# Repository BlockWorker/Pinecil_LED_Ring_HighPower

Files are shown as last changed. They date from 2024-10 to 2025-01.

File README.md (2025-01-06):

# High-Power Pinecil LED Ring

Inspired by [Herushan's original Pinecil LED ring](https://github.com/Herushan/Pinecil_LED_Ring). See the [full project documentation here](https://blockworker.de/pinecil-led-ring-901/).

This version is designed for three ~0.2W LEDs, resulting in almost 100 lumens of light output.

Features a dedicated LED driver module (to be installed inside the Pinecil case), the LED ring itself, as well as PWM dimming using a [modified version of IronOS](https://github.com/BlockWorker/IronOS-LED).

<center>



</center>

## Build one yourself

Of course, feel free to build your own LED ring based on the designs in this repository. Use them as they are, or modify them for your needs if you feel like it - either way, at your own risk.

The posts on my website offer a more detailed description of the project and [build process that you can follow along with](https://blockworker.de/pinecil-led-ring-build-922/).

The PCB designs are based on JLCPCB's design rules, so adjust them accordingly if you're using a different PCB service. The LED ring PCB is a 1.6mm aluminium core board, and the driver PCB is a 0.8mm 2-layer FR4 board.

Here is a table of the required components, with example parts and Mouser links:

| Reference | Description | Example Part |
| - | - | - |
| U1 | LM3407 LED Driver | [Texas Instruments LM3407MY](https://mou.sr/4eeUAvk) |
| D1 | Schottky Diode, >30V, SOD-323 | [Panjit SS0840WS](https://mou.sr/4a6Dr5q) |
| L1 | Inductor, 150µH, SMD 4 x 4 mm | [Taiyo Yuden NRS4018T151MDGJ](https://mou.sr/3PJLYSF) |
| C1 | Capacitor, 4.7µF 35V, SMD 0805 | [Murata GRM21BZ7YA475KE15](https://mou.sr/3Wa5xai) |
| C2 | Capacitor, 4.7µF 50V, SMD 1206 | [Murata GRM31CR71H475KA12](https://mou.sr/4gZpf0g) |
| C3 | Capacitor, 1µF >6.3V, SMD 0603 | [Samsung CL10B105KA8NNN](https://mou.sr/40pRb75) |
| R1 | Resistor, 4.7kΩ, SMD 0603 | [Bourns CR0603-FX-4701ELF](https://mou.sr/423VuaA) |
| R2 | Resistor, 3.09Ω, SMD 0603 | [Vishay CRCW06033R09FKEA](https://mou.sr/4fNpef5) |
| R3 | Resistor, 1kΩ, SMD 0603 | [Bourns CR0603-FX-1001ELF](https://mou.sr/3VS87BY) |
| R4 | Resistor, 40.2kΩ, SMD 0603 | [Bourns CR0603-FX-4022ELF](https://mou.sr/4h0pGrc) |
| (Ring) D1-D3 | MP-3030-120H LEDs | [Luminus MP-3030-120H-40-90](https://mou.sr/40ogQy9) |

Aside from these parts, you'll need some thin wires, a second soldering iron, and ideally a small PCB hot plate for reflow soldering (especially for soldering the LEDs to the aluminium-core ring PCB). The LM3407 chip also needs either a hot plate or a hot air gun to effectively solder its bottom thermal pad.

Equivalent replacements to these parts should work fine as well - though depending on your choice, you may need to change the PCB component footprints accordingly.

There are many LED options available in the [MP-3030-120H series](https://www.mouser.de/c/?q=mp-3030-120h), depending on your preferences. I went with 4000K colour temperature and CRI 90, for high-quality neutral white light.
Colour temperature options range from very warm 2200K to cold 6500K, and if you want some more brightness at the cost of "light quality", there are brighter CRI 80 variants available.

Of course, there are many other LED options out there that will work, though PCB adjustments may be needed for them. The design targets single-LED chips (around 3V per chip) and a current of 65mA.

If you'd like to use the LED dimming feature, you need to flash my [modified IronOS firmware](https://github.com/BlockWorker/IronOS-LED) onto your Pinecil and connect the "DIM" pad to the Pinecil PCB as shown on my website.
Alternatively, you can just force the ring to 100% brightness all the time, by connecting a jumper wire between the "DIM" pad and the "TP1" test point on the back side of the driver.

The driver circuit can be modified for up to 350mA LED current (see notes in the schematic and the [LM3407 datasheet](https://www.ti.com/lit/ds/symlink/lm3407.pdf)), but I haven't tested higher currents, and LED cooling may become a problem at higher power.

If you'd like to make the ring removable ([as seen on my website](https://blockworker.de/pinecil-led-ring-build-922/)), you'll need a very small 2-pin connector, e.g., the [Amphenol Minitek 0.8mm connector I used](https://www.amphenol-cs.com/product-series/minitek-0-80mm-wtb.html#). The header can be wired to the ring and glued onto its back using some epoxy. However, crimping the wire end of such a small connector is challenging - [I've made a post about my process for it here](https://blockworker.de/modular-audio-appendix-minitek-0-8mm-connectors-2055/). I don't recommend this for beginners though.

For questions or anything else, you can find me on the official PINE64 discord server (@blockworker).

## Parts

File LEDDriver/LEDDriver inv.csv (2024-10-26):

Id | Designator | Footprint | Quantity | Designation | Supplier and ref | Added | Have
1 | C1 | C_0805_2012Metric | 1 | 4.7µF 35V |  | v
2 | TP1 | TestPoint_Pad_D1.0mm | 1 | VCC |  |  | v
3 | U1 | MSOP-8-1EP_3x3mm_P0.65mm_EP1.73x1.85mm | 1 | LM3407MY |  | v
4 | R4 | R_0603_1608Metric | 1 | 40.2kΩ |  |  | v
5 | R3 | R_0603_1608Metric | 1 | 1kΩ |  |  | v
6 | R2 | R_0603_1608Metric | 1 | 3.09Ω |  | v
7 | R1 | R_0603_1608Metric | 1 | 4.7kΩ |  |  | v
8 | L1 | L_Taiyo-Yuden_NR-40xx_HandSolderingCompact | 1 | 150µH |  | v
9 | J5 | SolderWire-0.5sqmm_1x01_D0.9mm_OD2.1mm | 1 | GND |  |  | v
10 | J4 | SolderWire-0.5sqmm_1x01_D0.9mm_OD2.1mm | 1 | DIM |  |  | v
11 | J3 | SolderWire-0.5sqmm_1x01_D0.9mm_OD2.1mm | 1 | VIN |  |  | v
12 | J2 | SolderWire-0.5sqmm_1x01_D0.9mm_OD2.1mm | 1 | LED- |  |  | v
13 | J1 | SolderWire-0.5sqmm_1x01_D0.9mm_OD2.1mm | 1 | LED+ |  |  | v
14 | D1 | D_SOD-323_HandSoldering | 1 | SS0840WS |  |  | v
15 | C3 | C_0603_1608Metric | 1 | 1µF |  |  | v
16 | C2 | C_1206_3216Metric | 1 | 4.7µF 50V |  | v
17 | XX | XX | 3 | LED |  | v

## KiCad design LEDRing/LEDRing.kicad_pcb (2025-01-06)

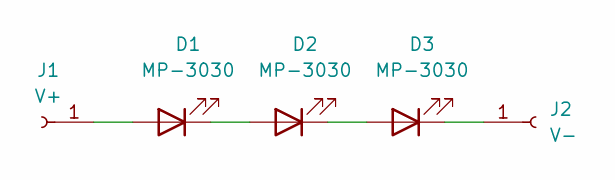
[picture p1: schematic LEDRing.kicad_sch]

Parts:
D1, D2, D3: MP-3030; LED_Luminus_MP-3030-1100_3.0x3.0mm
J1: V+; SolderWirePad_1x01_SMD_1x2mm
J2: V-; SolderWirePad_1x01_SMD_1x2mm

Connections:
unnamed: D1.2 (A), J1.1
unnamed: D1.1 (K), D2.2 (A)
unnamed: D2.1 (K), D3.2 (A)
unnamed: D3.1 (K), J2.1

Board: 2 copper layers, 6 parts (0 on the bottom side), 4 nets, no tracks yet.

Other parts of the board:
Logo: BW_Logo_Silk_5x3.2mm

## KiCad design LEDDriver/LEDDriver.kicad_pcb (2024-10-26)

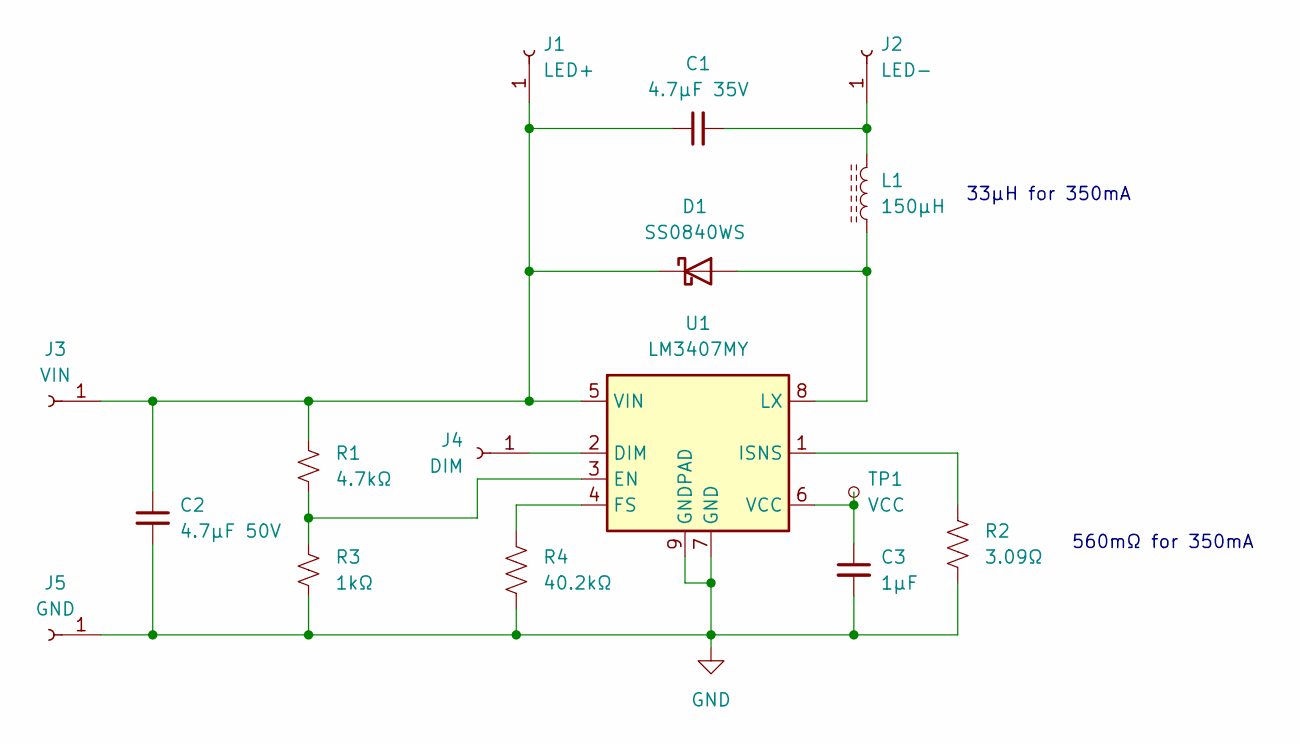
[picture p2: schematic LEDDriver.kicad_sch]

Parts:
C1: 4.7µF 35V; C_0805_2012Metric
C2: 4.7µF 50V; C_1206_3216Metric
C3: 1µF; C_0603_1608Metric
D1: SS0840WS; D_SOD-323_HandSoldering
J1: LED+; SolderWire-0.5sqmm_1x01_D0.9mm_OD2.1mm
J2: LED-; SolderWire-0.5sqmm_1x01_D0.9mm_OD2.1mm
J3: VIN; SolderWire-0.5sqmm_1x01_D0.9mm_OD2.1mm
J4: DIM; SolderWire-0.5sqmm_1x01_D0.9mm_OD2.1mm
J5: GND; SolderWire-0.5sqmm_1x01_D0.9mm_OD2.1mm
L1: 150µH; L_Taiyo-Yuden_NR-40xx_HandSolderingCompact
R1: 4.7kΩ; R_0603_1608Metric
R2: 3.09Ω; R_0603_1608Metric
R3: 1kΩ; R_0603_1608Metric
R4: 40.2kΩ; R_0603_1608Metric
TP1: VCC; TestPoint_Pad_D1.0mm
U1: LM3407MY; MSOP-8-1EP_3x3mm_P0.65mm_EP1.73x1.85mm

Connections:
GND: C2.2, C3.2, J5.1, R2.2, R3.2, R4.2, U1.7 (GND), U1.9 (GNDPAD)
unnamed: D1.2 (A), L1.1, U1.8 (LX)
unnamed: C1.1, C2.1, D1.1 (K), J1.1, J3.1, R1.1, U1.5 (VIN)
unnamed: C1.2, J2.1, L1.2
unnamed: J4.1, U1.2 (DIM)
unnamed: R1.2, R3.1, U1.3 (EN)
unnamed: R4.1, U1.4 (FS)
unnamed: R2.1, U1.1 (ISNS)
unnamed: C3.1, TP1.1, U1.6 (VCC)

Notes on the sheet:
33µH for 350mA
560mΩ for 350mA

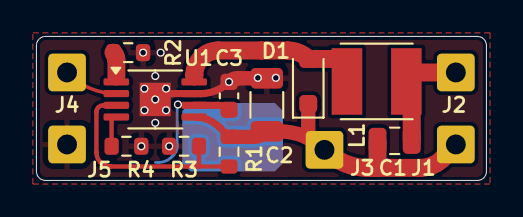
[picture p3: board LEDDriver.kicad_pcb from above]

Board: 2 copper layers, 25.0 x 8.0 mm, 16 parts (1 on the bottom side), 9 nets.

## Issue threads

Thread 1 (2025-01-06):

Extra diode options?

Mzter-Pink, 2025-01-06:
extra diode options for sayyy 650nm (night soldering to reduce eye strain(and tactical))!! im interested in helping though!!

BlockWorker, 2025-01-06:
I'm not sure if single-colour LEDs would be a good choice for lighting a workspace, white is really the best for that.

I designed the ring for Luminus MP-3030-120H LEDs, and went for a 4000K colour temperature with a CRI of 90, as a good-quality "neutral" white point (https://mou.sr/40ogQy9).

However, if you want something warmer for reduced eye strain, they have warm white options, for example 3000K (https://mou.sr/427Ero5), 2700K (https://mou.sr/4h6gB09), or even 2200K (https://mou.sr/3Pmc9ym).

Each of these also has a slightly brighter version with a CRI of 80 - basically brighter at the expense of light "quality".

Mzter-Pink, 2025-01-06:
I am planning on using my Pinecil v2(out for delivery as we speak) heavily in the automotive application and ive been thinking about adding both natural white and 650nm "deep red" to preserve night vision so you can toggle between "black-out" or natural white!!

ps: I've also been debating mounting the led's internally and running fiber optics to deliver the light to the workpiece!!

BlockWorker, 2025-01-06:
I see, that's an interesting use case. You can definitely use red LEDs, but if you want to switch between red and white light, you'd need to come up with a solution for that - my design only supports controlling and driving a single set of LEDs right now.

Regarding internal LED mounting - you could do that, though I'm not sure if it's any better. The current LED placement (a bit away from the iron towards the outside) already suffers from some shadow effects when you get closer to the workpiece, so putting fibre optics directly onto the iron would probably make those worse. Ideally you do want the light sources to be spaced out a bit, so the light comes in from an angle to avoid shadows.

Mzter-Pink, 2025-01-08:
I definitely see your point!!it would be possible to make the light ring modular  (just switch the module for 650nm or even 402nm(best guess) for hardening your solder mask) but the fiber optic design would more than likely take a case redesign along with some lensing and/or diffusers to achieve the optimal effect but my thought was to get the diodes away from the heat and increase reliability and longevity!

BlockWorker, 2025-01-08:
Yep, switching out the ring is definitely possible (especially if you attach a connector to it, like I did). It just takes a bit of effort.

As for getting the diodes away from the heat - the front end of the case, where the ring is mounted, really doesn't get too warm at all. From what I've seen so far, almost all of the heat experienced by the LEDs is from their own self-heating.

Closed 2025-01-22.

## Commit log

2024-10-26 Inventory done
    [LEDDriver inv.csv]
2025-01-06 Ring hole size increased
    [LEDRing.kicad_pcb, LEDRing.kicad_sch]

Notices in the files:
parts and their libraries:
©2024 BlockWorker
